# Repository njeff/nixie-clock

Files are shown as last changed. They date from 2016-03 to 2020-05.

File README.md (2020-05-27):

# Nixie Clock
This repository contains the KiCAD files for the PCB and the Atmel Studio files for the code.

If you plan on recreating this, I recommend changing the PCB design to use all SMD components and paying attention to high voltage clearance.

[Instructables](https://www.instructables.com/id/SMD-Nixie-Clock/) write up for this project.

Uses the following libraries:
- Zak Kemble's [millis](https://github.com/zkemble/millis) library
- akafugu's [DS3231](https://github.com/akafugu/ds_rtc_lib) RTC library

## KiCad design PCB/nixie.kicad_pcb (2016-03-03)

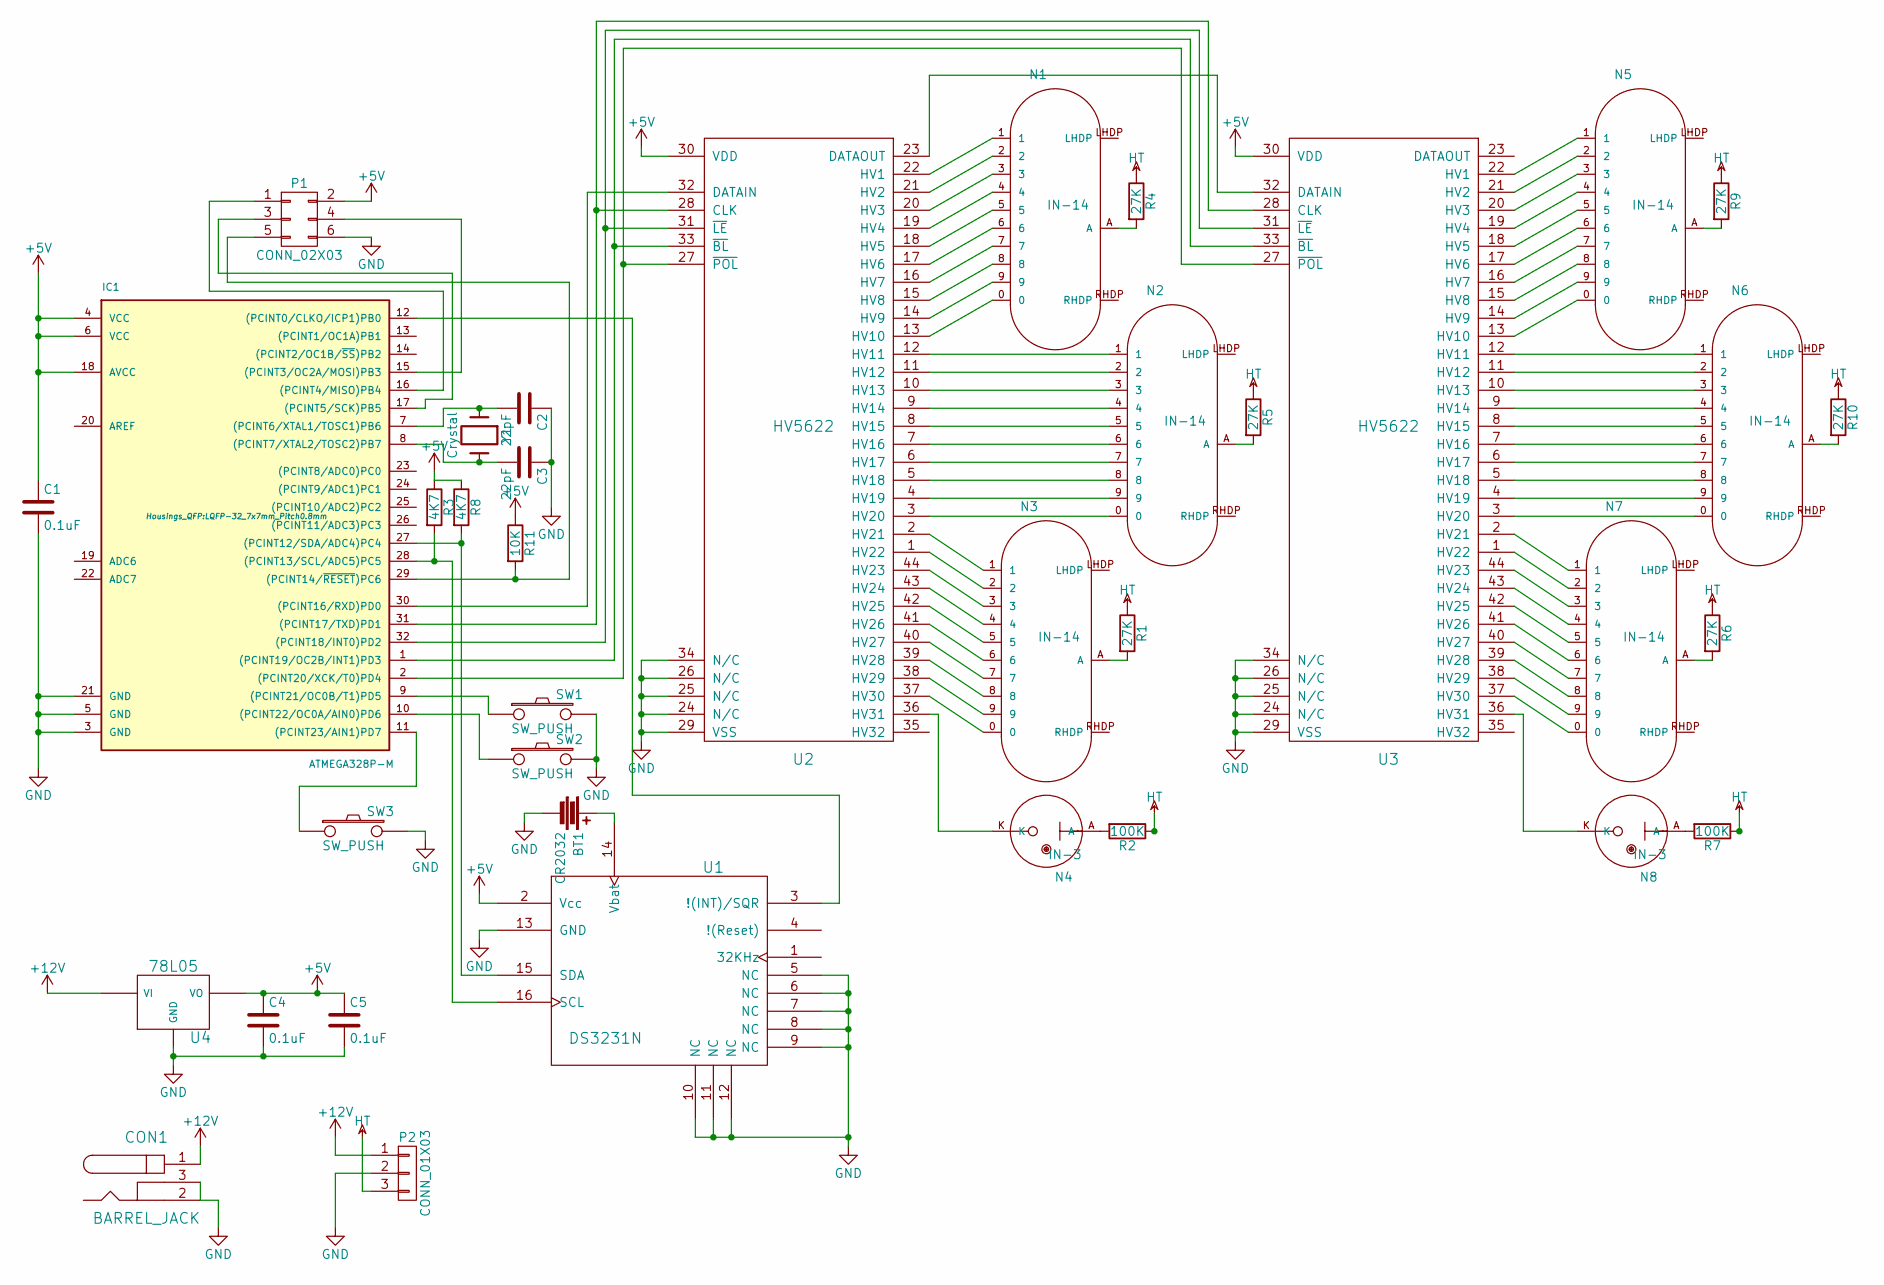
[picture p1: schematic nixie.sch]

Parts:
BT1: CR2032
C1, C4, C5: 0.1uF; C_Disc_D3_P2.5
C2, C3: 22pF; C_Disc_D3_P2.5
CON1: BARREL_JACK
IC1: ATMEGA328P-M; LQFP-32_7x7mm_Pitch0.8mm
N1, N2, N3, N5, N6, N7: IN-14; russian-nixies-IN-14
N4, N8: IN-3; russian-nixies-IN-3
P1: CONN_02X03; Pin_Header_Straight_2x03
P2: CONN_01X03; Pin_Header_Straight_1x03
R1, R4, R5, R6, R9, R10: 27K; Resistor_Vertical_RM5mm
R2, R7: 100K; Resistor_Vertical_RM5mm
R3, R8: 4K7; Resistor_Vertical_RM5mm
R11: 10K; Resistor_Vertical_RM5mm
SW1, SW2, SW3: SW_PUSH; SW_Tactile_SPST_Angled
U1: DS3231N; SO-16-L
U2, U3: HV5622; LQFP-44_10x10mm_Pitch0.8mm
U4: 78L05; TO-92_Inline_Wide
Y1: Crystal; Crystal_HC49-U_Vertical

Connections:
+5V: C1.1, C4.1, C5.1, IC1.4 (VCC), IC1.6 (VCC), IC1.18 (AVCC), P1.2, R3.1, R8.1, R11.1, U1.2 (Vcc), U2.30 (VDD), U3.30 (VDD), U4.1 (VO)
+12V: CON1.1, P2.1, U4.3 (VI)
GND: BT1.2, C1.2, C2.1, C3.1, C4.2, C5.2, CON1.2, CON1.3, IC1.3 (GND), IC1.5 (GND), IC1.21 (GND), P1.6, P2.2, SW1.2, SW2.2, SW3.2, U1.5 (NC), U1.6 (NC), U1.7 (NC), U1.8 (NC), U1.9 (NC), U1.10 (NC), U1.11 (NC), U1.12 (NC), U1.13 (GND), U2.24 (N/C), U2.25 (N/C), U2.26 (N/C), U2.29 (VSS), U2.34 (N/C), U3.24 (N/C), U3.25 (N/C), U3.26 (N/C), U3.29 (VSS), U3.34 (N/C), U4.2 (GND)
HT: P2.3, R1.1, R2.1, R4.1, R5.1, R6.1, R7.1, R9.1, R10.1
unnamed: BT1.1, U1.14 (Vbat)
unnamed: C2.2, IC1.7 ((PCINT6/XTAL1/TOSC1)PB6), Y1.1
unnamed: C3.2, IC1.8 ((PCINT7/XTAL2/TOSC2)PB7), Y1.2
unnamed: IC1.1 ((PCINT19/OC2B/INT1)PD3), U2.33 (~BL), U3.33 (~BL)
unnamed: IC1.2 ((PCINT20/XCK/T0)PD4), U2.27 (~POL), U3.27 (~POL)
unnamed: IC1.9 ((PCINT21/OC0B/T1)PD5), SW1.1
unnamed: IC1.10 ((PCINT22/OC0A/AIN0)PD6), SW2.1
unnamed: IC1.11 ((PCINT23/AIN1)PD7), SW3.1
unnamed: IC1.12 ((PCINT0/CLKO/ICP1)PB0), U1.3 (!(INT)/SQR)
unnamed: IC1.15 ((PCINT3/OC2A/MOSI)PB3), P1.4
unnamed: IC1.16 ((PCINT4/MISO)PB4), P1.1
unnamed: IC1.17 ((PCINT5/SCK)PB5), P1.3
unnamed: IC1.27 ((PCINT12/SDA/ADC4)PC4), R8.2, U1.15 (SDA)
unnamed: IC1.28 ((PCINT13/SCL/ADC5)PC5), R3.2, U1.16 (SCL)
unnamed: IC1.29 ((PCINT14/~RESET~)PC6), P1.5, R11.2
unnamed: IC1.30 ((PCINT16/RXD)PD0), U2.32 (DATAIN)
unnamed: IC1.31 ((PCINT17/TXD)PD1), U2.28 (CLK), U3.28 (CLK)
unnamed: IC1.32 ((PCINT18/INT0)PD2), U2.31 (~LE), U3.31 (~LE)
unnamed: N1.0, U2.13 (HV10)
unnamed: N1.1, U2.22 (HV1)
unnamed: N1.2, U2.21 (HV2)
unnamed: N1.3, U2.20 (HV3)
unnamed: N1.4, U2.19 (HV4)
unnamed: N1.5, U2.18 (HV5)
unnamed: N1.6, U2.17 (HV6)
unnamed: N1.7, U2.16 (HV7)
unnamed: N1.8, U2.15 (HV8)
unnamed: N1.9, U2.14 (HV9)
unnamed: N1.A, R4.2
unnamed: N2.0, U2.3 (HV20)
unnamed: N2.1, U2.12 (HV11)
unnamed: N2.2, U2.11 (HV12)
unnamed: N2.3, U2.10 (HV13)
unnamed: N2.4, U2.9 (HV14)
unnamed: N2.5, U2.8 (HV15)
unnamed: N2.6, U2.7 (HV16)
unnamed: N2.7, U2.6 (HV17)
unnamed: N2.8, U2.5 (HV18)
unnamed: N2.9, U2.4 (HV19)
unnamed: N2.A, R5.2
unnamed: N3.0, U2.37 (HV30)
unnamed: N3.1, U2.2 (HV21)
unnamed: N3.2, U2.1 (HV22)
unnamed: N3.3, U2.44 (HV23)
unnamed: N3.4, U2.43 (HV24)
unnamed: N3.5, U2.42 (HV25)
unnamed: N3.6, U2.41 (HV26)
unnamed: N3.7, U2.40 (HV27)
unnamed: N3.8, U2.39 (HV28)
unnamed: N3.9, U2.38 (HV29)
unnamed: N3.A, R1.2
unnamed: N4.A, R2.2
unnamed: N4.K, U2.36 (HV31)
unnamed: N5.0, U3.13 (HV10)
unnamed: N5.1, U3.22 (HV1)
unnamed: N5.2, U3.21 (HV2)
unnamed: N5.3, U3.20 (HV3)
unnamed: N5.4, U3.19 (HV4)
unnamed: N5.5, U3.18 (HV5)
unnamed: N5.6, U3.17 (HV6)
unnamed: N5.7, U3.16 (HV7)
unnamed: N5.8, U3.15 (HV8)
unnamed: N5.9, U3.14 (HV9)
unnamed: N5.A, R9.2
unnamed: N6.0, U3.3 (HV20)
unnamed: N6.1, U3.12 (HV11)
unnamed: N6.2, U3.11 (HV12)
unnamed: N6.3, U3.10 (HV13)
unnamed: N6.4, U3.9 (HV14)
unnamed: N6.5, U3.8 (HV15)
unnamed: N6.6, U3.7 (HV16)
unnamed: N6.7, U3.6 (HV17)
unnamed: N6.8, U3.5 (HV18)
unnamed: N6.9, U3.4 (HV19)
unnamed: N6.A, R10.2
unnamed: N7.0, U3.37 (HV30)
unnamed: N7.1, U3.2 (HV21)
unnamed: N7.2, U3.1 (HV22)
unnamed: N7.3, U3.44 (HV23)
unnamed: N7.4, U3.43 (HV24)
unnamed: N7.5, U3.42 (HV25)
unnamed: N7.6, U3.41 (HV26)
unnamed: N7.7, U3.40 (HV27)
unnamed: N7.8, U3.39 (HV28)
unnamed: N7.9, U3.38 (HV29)
unnamed: N7.A, R6.2
unnamed: N8.A, R7.2
unnamed: N8.K, U3.36 (HV31)
unnamed: U2.23 (DATAOUT), U3.32 (DATAIN)

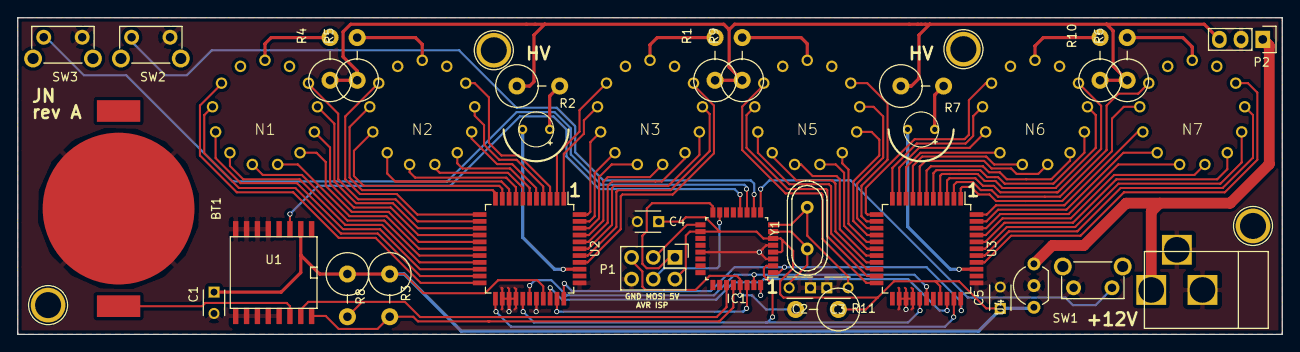
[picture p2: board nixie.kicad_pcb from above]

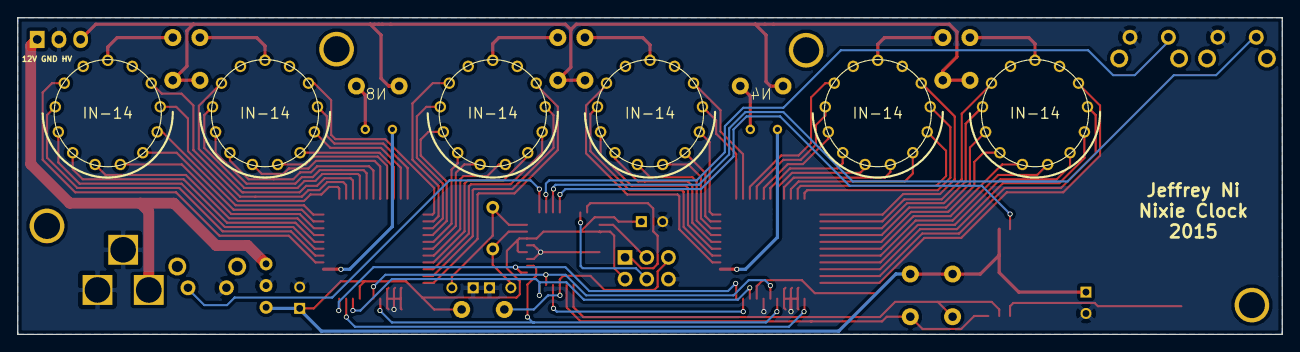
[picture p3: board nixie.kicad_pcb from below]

Board: 2 copper layers, 148.1 x 37.1 mm, 37 parts (6 on the bottom side), 93 nets.

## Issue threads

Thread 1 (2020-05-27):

Error when trying to build the NixieCode in AtmelStudio6.1

FlorianPix, 2020-05-27:
I built a NixieClock with your instructable but cant write code to the ATMega328P.
What I did is install AtmelStudio6.1, open your project connecting the ARCELI Atmel BEI AVRISP mkii XPII AVR ISP mk2 USB AVRISP-In-System-Programmer and then try to build the solution.

Error	1	#error "F_CPU not defined!"
C:\Users\Florian Pix\Documents\Programme\NixieCode\NixieCode\millis.c	16	3	NixieCode
Error	2	#error "Bad F_CPU setting (<256 or >=32640000)"
C:\Users\Florian Pix\Documents\Programme\NixieCode\NixieCode\millis.c	20	3	NixieCode
Error	3	'F_CPU' undeclared (first use in this function)
C:\Users\Florian Pix\Documents\Programme\NixieCode\NixieCode\millis.c	121	14	NixieCode

What am I doing wrong ? I am new to Microcontroller programming.

njeff, 2020-05-27:
Hi, you need to define the frequency of the microcontroller.
In Atmel Studio, you can do this by going to Project ->NixieCode Properties -> Toolchain -> AVR/GNU C Compiler -> Symbols.
Here, you should press the little + icon in the "Defined Symbols" box to add a symbol, and add F_CPU=8000000UL.

FlorianPix, 2020-05-27:
Hi :) thanks for the quick response your answer resolved this issue but a new error rose. D:
The USB driver attach timed out.
Do you think this is due to me not properly soldering something or do I need to install a driver for flashing or something else?

Timestamp:	2020-05-27 21:42:20.481
Severity:		ERROR
ComponentId:	20100
StatusCode:	1
ModuleName:	TCF (TCF command: Tool:connect failed.)

njeff, 2020-05-27:
You may need to install a driver; does the programmer show up under your Device Manager as AVRISP? If not you will probably need to find the driver for it and install it.

FlorianPix, 2020-05-27:
It shows up as Jungo - WinDriver im gonna try deinstalling the drivers, rebooting and installing everything again. Because some forums suggest that you should not attach the AVRISP to the computer prior to installing the drivers that come with Atmel Studio but I did. Lets see.
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osh

alexanderkrause, 2020-05-28:
Hi this is Florian Pix again from a friends account. I got it to apperantly connect and read something.
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
But I get this error:

Timestamp:	2020-05-28 19:39:59.928
Severity:		ERROR
ComponentId:	20100
StatusCode:	131101
ModuleName:	TCF (TCF command: Device:startSession failed.)

Unexpected signature 0x00535353 (expected 0x001e950f).

In forums they said I could adjust the ISP Clock but I tried a lot of values and nothing seems to work. Any ideas ?

njeff, 2020-05-28:
I'm taking a look at the solutions people are putting on the forums; what speeds have you tried? Maybe 100kHz would work? Can you read any other data from the microcontroller (like fuse data)?

You may also try flashing with avrdude.

alexanderkrause, 2020-05-28:
Yes we have tried 100kHz.
No we cant read any fuse data :(

We found an error with the power supply and now the clock looks like this:
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
Do you have an idea where there might be a faulty connection or is this the default behaviour before flashing the atmega ?

njeff, 2020-05-28:
Hard to say but that is probably fine; I'm not sure what state the shift registers default to when powered on and have no data. All the channels could possibly be on and the clock would look like your picture shown.

One thing to check hardware-wise is make sure your high voltage and low voltage systems are well isolated. Residual flux from soldering could cause unwanted connections and you want to be sure everything is well cleaned. When you tried to program the device earlier, did you have the high voltage applied? Have you tried programming other AVR devices with the programmer? I would recommend trying to see if other devices flash to see if this is just a problem with this specific setup.

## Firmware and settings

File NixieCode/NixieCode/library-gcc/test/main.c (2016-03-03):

/*
 * DS RTC Library: DS1307 and DS3231 driver library
 * (C) 2011 Akafugu Corporation
 *
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
 */

#include <stdio.h>

#include <avr/io.h>
#include <avr/interrupt.h>
#include <util/delay.h>

#include "../twi.h"
#include "../rtc.h"

#include "uart.h"

#define LED_BIT PB5
#define LED_DDR DDRB
#define LED_PORT PORTB
#define LED_HIGH LED_PORT |= _BV(LED_BIT)
#define LED_HIGH LED_PORT |= _BV(LED_BIT)
#define LED_LOW  LED_PORT &= ~(_BV(LED_BIT))

void read_rtc(void)
{
	if(rtc_is_ds3231()) {
		int8_t t;
		uint8_t f;
		ds3231_get_temp_int(&t, &f);
	}
	else {
		uint8_t hour, min, sec;
		rtc_get_time_s(&hour, &min, &sec);	
	}
}

void main(void) __attribute__ ((noreturn));

void main(void)
{
	struct tm* t = NULL;
	char buf[32];
	uint8_t hour, min, sec;

	uartInit();
	uartSetBaudRate(9600);
	uartSendString("DS RTC Library Test\n");

	LED_DDR  |= _BV(LED_BIT); // indicator led

	for (int i = 0; i < 5; i++) {
		LED_HIGH;
		_delay_ms(100);
		LED_LOW;
		_delay_ms(100);
	}

	uartSendString("Before Init\n");
	twi_init_master();
	rtc_init();
	rtc_set_time_s(12, 0, 50);

	uartSendString("After Init\n");
	if (rtc_is_ds1307())
		uartSendString("DS1307\n");
	else
		uartSendString("DS3231\n");

	rtc_set_alarm_s(12, 1, 0);
	
	rtc_get_alarm_s(&hour, &min, &sec);

	sprintf(buf, "Alarm is set -%d:%d:%d-\n", hour, min, sec);
	uartSendString(buf);	
	uartSendString("---\n");
	uartSendString("---\n");
	uartSendString("---\n");

	while (1) {
		t = rtc_get_time();

		sprintf(buf, "%d:%d:%d\n", t->hour, t->min, t->sec);
		uartSendString(buf);
		uartSendString("---\n");

		if (rtc_check_alarm())
			uartSendString("ALARM!\n");

	   	_delay_ms(500);
	}
}

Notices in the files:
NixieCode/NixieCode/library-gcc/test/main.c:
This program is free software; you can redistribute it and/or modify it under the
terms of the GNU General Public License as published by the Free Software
